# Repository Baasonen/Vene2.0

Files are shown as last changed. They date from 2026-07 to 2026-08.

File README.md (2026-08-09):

<p align="center">
  Vene2.0
</p>

# Vene 2.0

Next evolution of the VENE project, with longer range LoRa communication and improved electronics design. Everything designed to be easily customizable and 3D printed.

## Performance

| Spec | Value |
|---|---|
| Radio Range | ?? km |
| Max Range | ?? km |
| Runtime | ?? min |
| Length | 0.85 m |
| Weight (without payload) | ~3 kg |
| Payload Capacity | ?? kg |
| Payload Dimensions | 130 × 250 × 60 mm* |
| Battery | 3S 6 Ah LiPo |

*Taller height possible with a custom lid

## VGUI2

<p align="center">
  VGUI2
</p>

---

Custom control software for Vene2.0 with multiple map and telemetry options, all easily modifiable.

- Plug & Play operation
- Flexible controller input options
- Route & Scan pattern editing
- Live telemetry & control

***

### Required Hardware

**Boat**
- ESP32
- RFM95W
- u-blox NEO GPS module (NEO-6M currently used; other UBX modules are plug-and-play compatible)
- BNO085
- 3S LiPo
- Generic BLDC motor and ESC
- LiPo → 5V buck converter
- Propeller shaft (RC stuffing box)
- APA106 LEDs (2×, 8 mm package)

**Receiver**
- ESP32
- RFM95W

## Gallery

<p align="center">
  <a href="https://youtu.be/8FJDHWQ4yFw">
    
  </a>
  <a href="https://youtu.be/eb7XCqz7wDQ">
    
  </a>
</p>

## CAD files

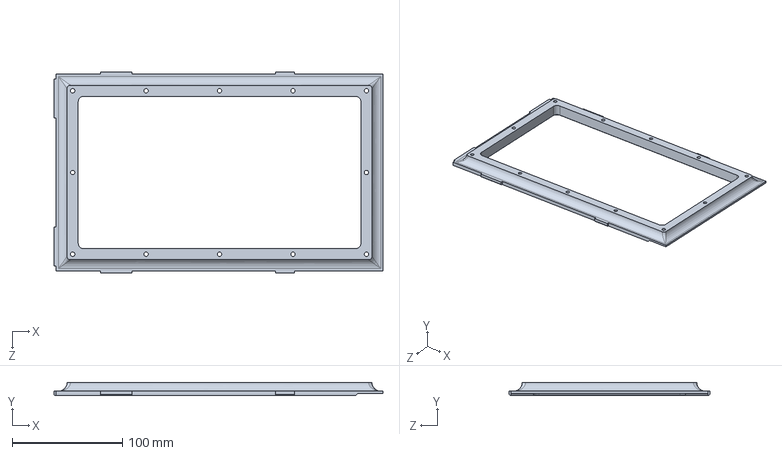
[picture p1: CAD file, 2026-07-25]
CAD/MAIN_HATCH.SLDPRT
297.9 x 12.0 x 181.8 mm

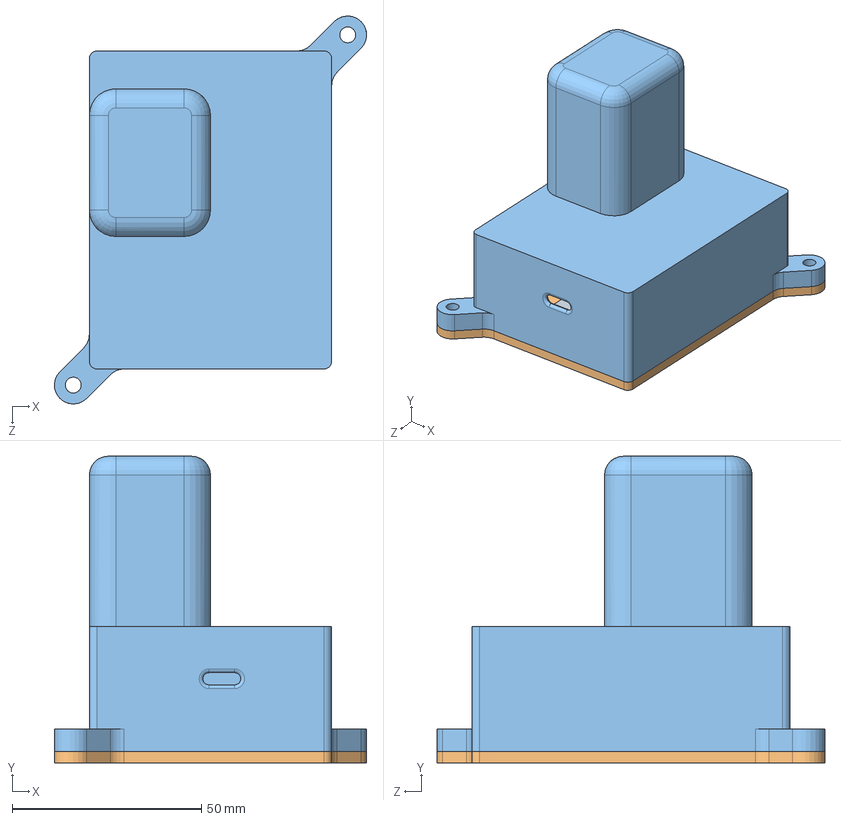
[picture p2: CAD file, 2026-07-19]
CAD/REC_HOUSING.SLDASM
82.5 x 81.0 x 102.5 mm
REC_HOUSING_TOP
REC_HOUSING_BOTTOM
REC_HOLDER

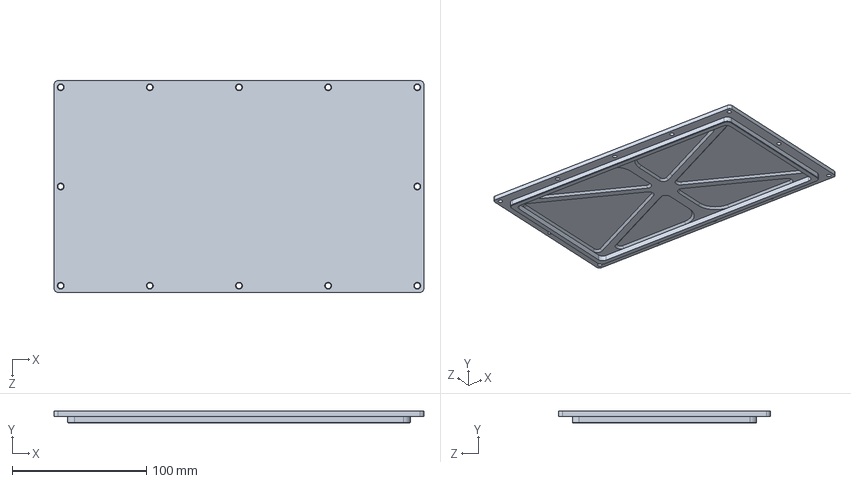
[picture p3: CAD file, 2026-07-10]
CAD/MAIN_HATCH_COVER.SLDPRT
276.0 x 9.00 x 158.0 mm

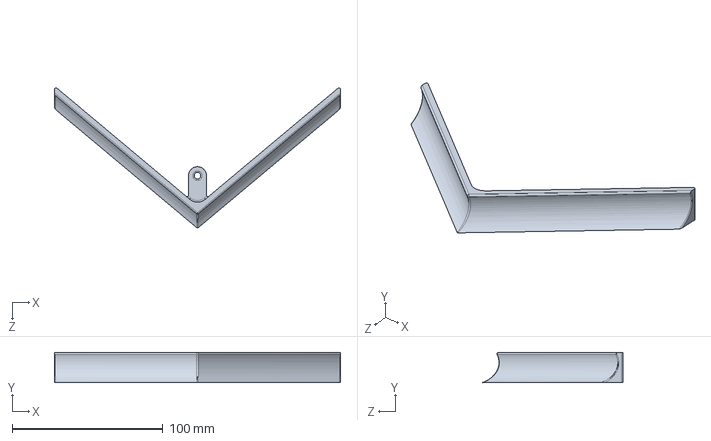
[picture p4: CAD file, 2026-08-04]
CAD/BOW_PLOW.SLDPRT
190.0 x 20.0 x 93.2 mm

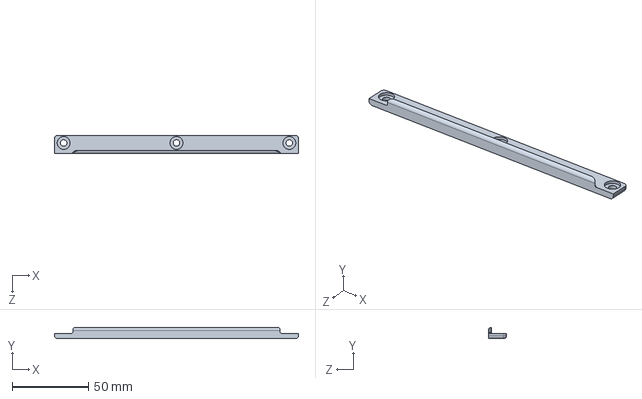
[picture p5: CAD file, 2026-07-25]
CAD/HATCH_BRIM_REAR.SLDPRT
160.0 x 7.50 x 12.0 mm

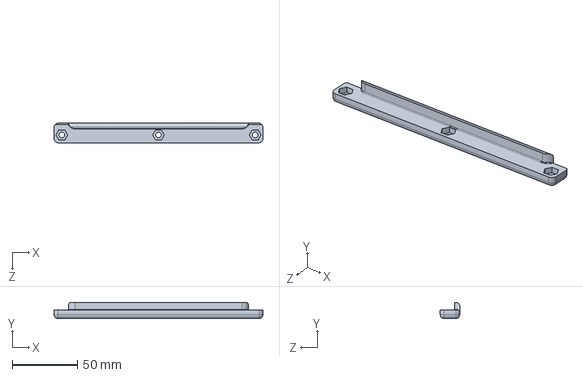
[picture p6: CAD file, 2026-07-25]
CAD/HATCH_BRIM_FRONT.SLDPRT
160.0 x 12.5 x 15.0 mm

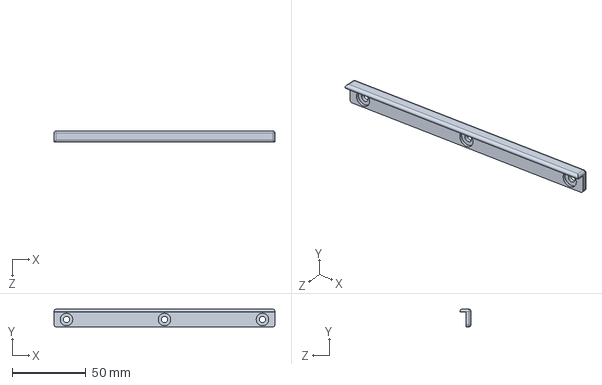
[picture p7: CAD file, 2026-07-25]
CAD/HATCH_BRIM_SIDE.SLDPRT
150.0 x 12.0 x 7.50 mm

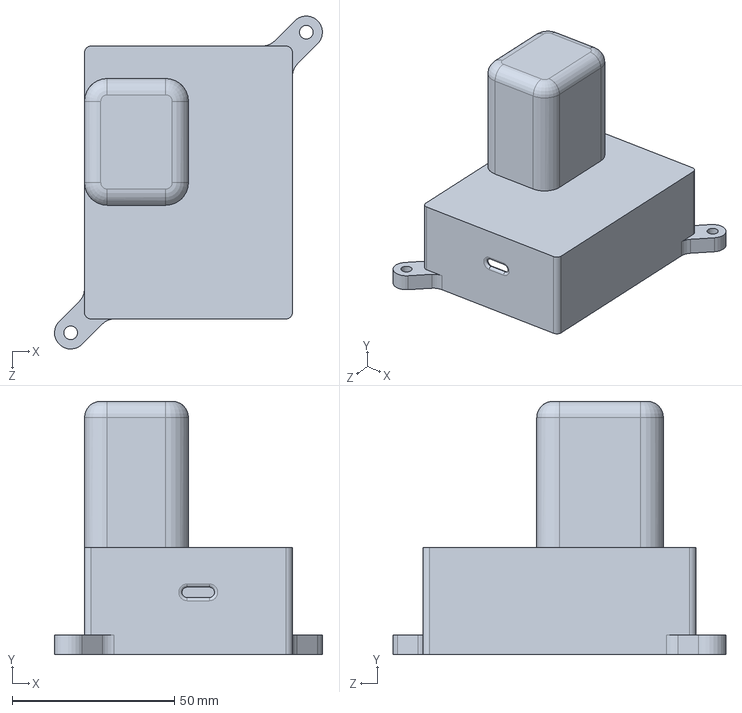
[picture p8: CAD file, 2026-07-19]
CAD/REC_HOUSING_TOP.SLDPRT
82.5 x 78.0 x 102.5 mm

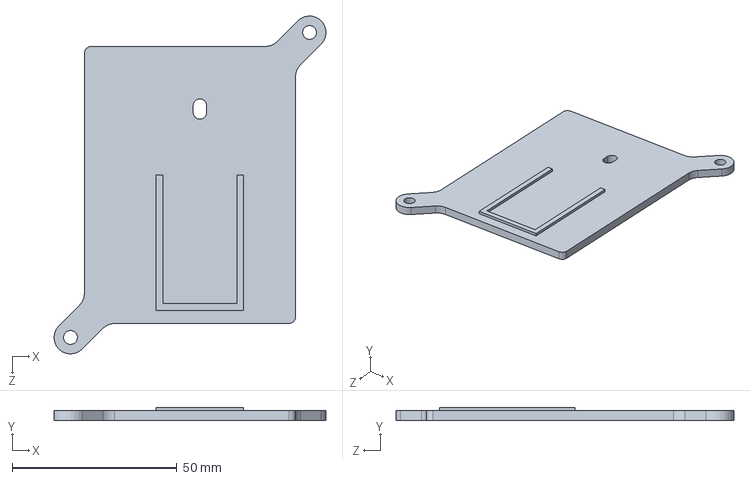
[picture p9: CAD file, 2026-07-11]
CAD/REC_HOUSING_BOTTOM.SLDPRT
82.5 x 4.00 x 102.5 mm

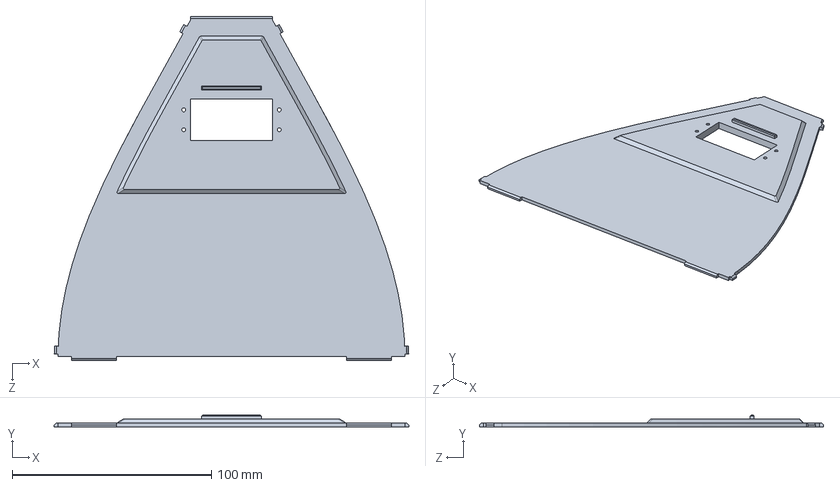
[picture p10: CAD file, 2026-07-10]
CAD/AFT_DECK.SLDPRT
178.1 x 6.00 x 172.8 mm

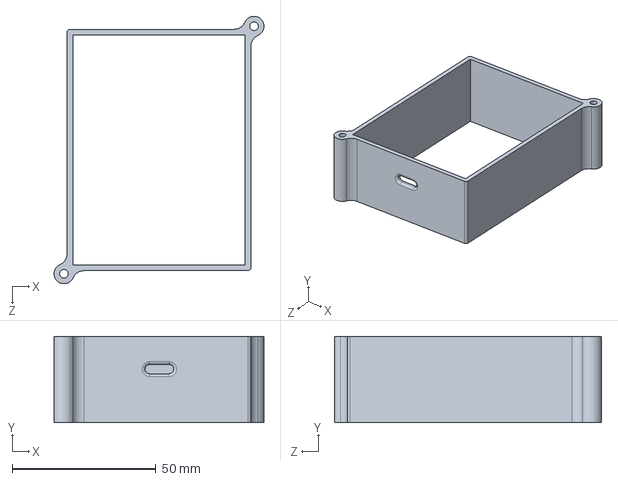
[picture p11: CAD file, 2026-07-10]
CAD/RECEIVER_HOUSING_BASE.SLDPRT
73.1 x 30.0 x 93.1 mm

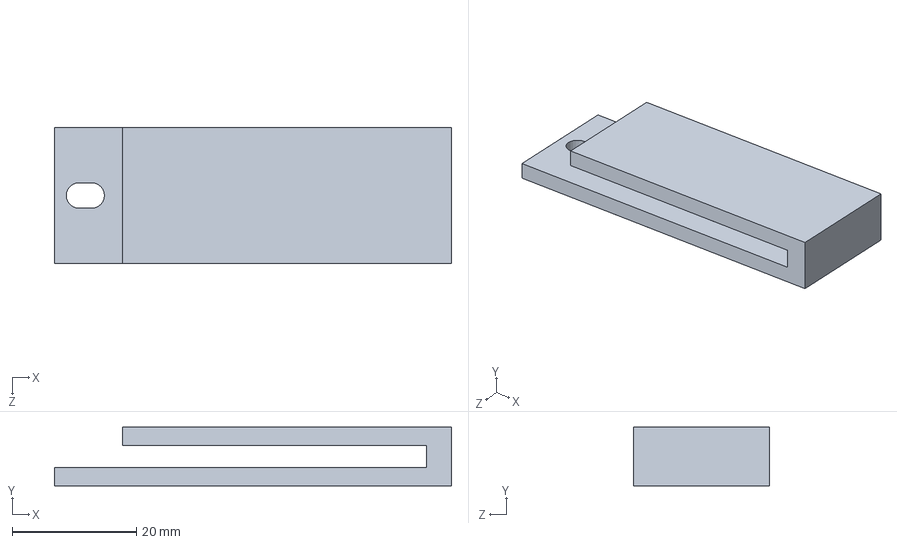
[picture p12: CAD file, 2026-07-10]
CAD/REC_HOLDER.SLDPRT
64.0 x 9.50 x 22.0 mm

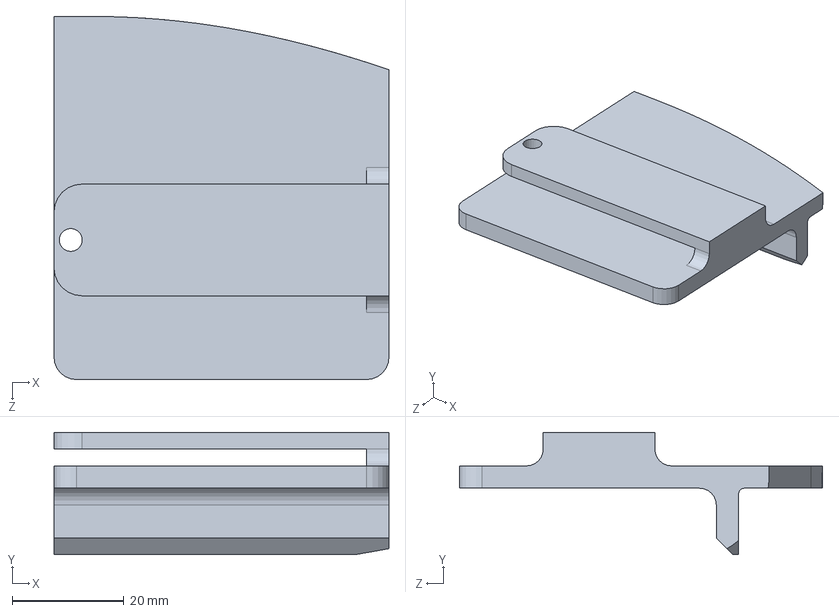
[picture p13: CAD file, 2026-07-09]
CAD/ESP_HOLDER.SLDPRT
60.0 x 21.9 x 65.0 mm

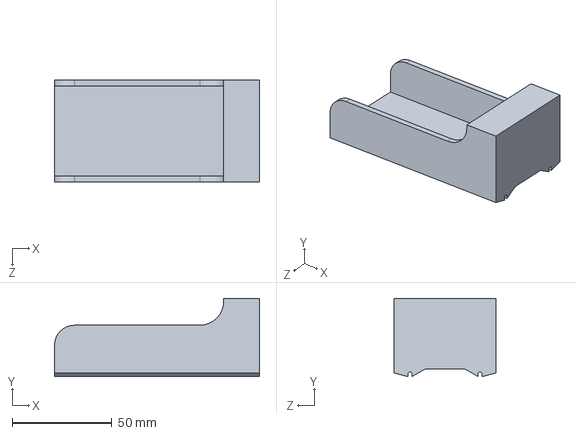
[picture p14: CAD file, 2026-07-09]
CAD/BATTER_HOLDER.SLDPRT
103.0 x 39.4 x 51.0 mm

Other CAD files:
CAD/VENE.SLDASM
CAD/HULLBOW.SLDPRT
CAD/MAST_DECK_ATTACHMENT.SLDPRT
CAD/HULLAFT_2.SLDPRT
CAD/AFT_DECK.STL
CAD/AFT_DECK_GUIDE.SLDPRT
CAD/BATTER_HOLDER.STL
CAD/BOW_PLOW.STL
CAD/Body1.SLDPRT
CAD/Body2.SLDPRT
CAD/ESP_HOLDER.STL
CAD/GPS_SHROUD.SLDPRT
CAD/GPS_SHROUD.STL
CAD/HATCH_BRIM_FRONT.STL
CAD/HATCH_BRIM_REAR.STL
CAD/HATCH_BRIM_SIDE.STL
CAD/HULLAFT_2.STL
CAD/HULLBOW.STL
CAD/HULLMID.SLDPRT
CAD/HULLMID.STL
CAD/LORA_DOME.SLDPRT
CAD/LORA_DOME.STL
CAD/MAIN_HATCH.STL
CAD/MAIN_HATCH_COVER.STL
CAD/MAST.SLDPRT
CAD/MAST_DECK_ATTACHMENT.STL
CAD/MAST_END.SLDPRT
CAD/MAST_END.STL
CAD/MAST_END_COVER.SLDPRT
CAD/MAST_END_COVER.STL
CAD/MOTORBASE1.SLDPRT
CAD/MOTORBASE1.STL
CAD/MOTORMOUNT_GUIDE.SLDPRT
CAD/MOTORMOUNT_GUIDE.STL
CAD/MOTORPLACEHOLDER.SLDPRT
CAD/NEO_6M_ANTENNA_BRACKET.SLDPRT
CAD/NEO_6M_ANTENNA_BRACKET.STL
CAD/NEO_6M_BRACKET.SLDPRT
CAD/NEO_6M_BRACKET.STL
CAD/PROP_COLLIDER.SLDPRT
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

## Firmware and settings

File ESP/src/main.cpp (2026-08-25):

#include <Arduino.h>
#include <ESP32Servo.h>
#include <Preferences.h>

#include "esp_system.h"
#include "esp_task_wdt.h"

#include "freertos/FreeRTOS.h"
#include "freertos/task.h"
#include "freertos/queue.h"
#include "freertos/semphr.h"

#include "magnetometer.h"
#include "gps.h"
#include "lora.h"
#include "state.h"
#include "control.h"
#include "wifiComm.h"
#include "navigation.h"
#include "errors.h"
#include "autopilot.h"
#include "led.h"
#include "LKF.h"
#include "tuning.h"

#define WDT_TIMEOUT 5

Preferences prefs;

State globalState = {0};
SemaphoreHandle_t stateMutex;
QueueHandle_t sensorQueue;

// CORE 1 | PRIORITY 4 | 50HZ
void sensorTask(void* pv)
{
    TickType_t xLastWakeTime = xTaskGetTickCount();
    const TickType_t xPeriod = pdMS_TO_TICKS(20);

    for(;;)
    {
        vTaskDelayUntil(&xLastWakeTime, xPeriod);

        SensorData data;
        data.gps = getGPS();
        data.mag = getMagnetometer();

        data.kf = LKFUpdate(data.gps, data.mag);

        xQueueOverwrite(sensorQueue, &data);

        Battery newBatt = getBattery();

        if (xSemaphoreTake(stateMutex, pdMS_TO_TICKS(10)) == pdTRUE)
        {
            globalState.battery = newBatt;

            xSemaphoreGive(stateMutex);
        }
    }
}

// CORE 1 | PRIORITY 3 | 20HZ
void controlTask(void* pv)
{
    esp_task_wdt_add(NULL);
 
    TickType_t xLastWakeTime = xTaskGetTickCount();
    const TickType_t xPeriod = pdMS_TO_TICKS(50); 
    SensorData sensors = {};
    SystemStatus status = {};
    ManualControls manual = {};
    Route route  = {};

    uint8_t lastMode = 255;
 
    for (;;)
    {
        vTaskDelayUntil(&xLastWakeTime, xPeriod);
        esp_task_wdt_reset();
 
        xQueuePeek(sensorQueue, &sensors, 0);

        if (xSemaphoreTake(stateMutex, pdMS_TO_TICKS(10)) == pdTRUE)
        {
            status = globalState.status;
            manual = globalState.manual;
 
            route = globalState.route;
            globalState.route.newRouteAvailable = false;
 
            xSemaphoreGive(stateMutex);
        }
 
        uint8_t mode = validateMode(status, sensors);

        if (mode != lastMode) {resetSteering();} // Reset steering PI controller on mode change 

        bool justArmed = (mode != 0) && !status.ctrlArmed;
 
        switch (mode)
        {
            case 0: // STOP
                turnRudder(0);
                setThrottle(0);
                break;
 
            case 1: // MANUAL
                turnRudder(manual.rudder);
                setThrottle(manual.throttle);
                break;
 
            case 2: // AUTOPILOT
                if (runAutopilot(status, sensors, route)) {mode = 0;}

                break;
 
            case 3: // RETURN HOME
                
                if (distanceToPoint(status.home.lat, status.home.lon, sensors.kf.lat, sensors.kf.lon) > HOME_TRESHOLD_M)
                {
                    setThrottle(status.APThrottle);
                    steerTo(headingToPoint(sensors.kf.lat, sensors.kf.lon, status.home.lat, status.home.lon));
                }
                else
                {
                    turnRudder(0);
                    setThrottle(0);
                }

                break;

            case 4: // COURSE HOLD
                steerTo(status.targetCourse);
                setThrottle(status.APThrottle);

                break;
 
            default:
                turnRudder(0);
                setThrottle(0);
                break;
        }
 
        if (xSemaphoreTake(stateMutex, pdMS_TO_TICKS(10)) == pdTRUE)
        {
            globalState.sensors = sensors;
            globalState.status.mode = mode;
            globalState.status.targetWaypoint = status.targetWaypoint;

            if (justArmed) {globalState.status.ctrlArmed = true;}
            
            xSemaphoreGive(stateMutex);
        }

        lastMode = mode;
    }
}

// CORE 1 | PRIORITY 2 | 20HZ
void wifiTask(void* pv)
{
    for(;;)
    {
        WiFiReadIncoming(stateMutex);
        vTaskDelay(pdMS_TO_TICKS(50));
    }
}

// CORE 0 | PRIORITY 1 | 0.5 HZ
void diagTask(void* pv)
{
    uint32_t startMillis = millis();

    for(;;)
    {
        vTaskDelay(pdMS_TO_TICKS(2000));

        SensorData sensors = {};
        SystemStatus status = {};
        Battery batt = {};

        xQueuePeek(sensorQueue, &sensors, 0);

        if (xSemaphoreTake(stateMutex, pdMS_TO_TICKS(10)) == pdTRUE)
        {
            status = globalState.status;
            batt = globalState.battery;

            xSemaphoreGive(stateMutex);
        }

        if (millis() - startMillis > 10000)
        {
            Serial.println("\n--- VENE 2.0 ---");
            Serial.printf("Mode:    %u\n", status.mode);
            Serial.printf("GPS:     [%s]  %.6f, %.6f  Sats: %d  HACC: %.2f KF POS STD: %.2f\n",
                          sensors.kf.valid ? "OK " : "BAD",
                          sensors.kf.lat, sensors.kf.lon,
                          sensors.gps.satellites, sensors.gps.hAccM, sensors.kf.posStdM);
            Serial.printf("KF NIS: pos: %.2f vel: %.2f\n", sensors.kf.posNISAvg, sensors.kf.velNIS);
            Serial.printf("Heading: [%s]  %.1f deg  Acc: %u/3\n",
                          sensors.mag.valid ? "OK " : "BAD",
                          sensors.mag.heading, sensors.mag.accuracy);
            Serial.printf("Time: [%s] %d\n", sensors.gps.utcTimeValid ? "GPS" : "REC", status.unixTime);
            Serial.printf("Comms:   LoRa TO: %s  WiFi TO: %s\n",
                          status.loraTimeout ? "YES" : "NO",
                          status.wifiTimeout ? "YES" : "NO");
            Serial.printf("LoRa RSSI: %i dBm\n\n", status.loraRSSI);
            Serial.printf("Battery: %.2f, %.2f, %.2f\n", batt.c1F, batt.c2F, batt.c3F);
            Serial.printf("Errors: 0x%08X\n", (unsigned long)status.errorCode);
            //printActiveErrors();
            Serial.println("----------------");
        }
    }
}

void ledTask(void* pv)
{
    // LED 0: Top
    // LED 1: Bottom

    static LedDoubleFlash bottomBlink;
    static LedPulse bottomCritBlink;
    static LedPulse topSlowBlink;

    static bool dBlink = false;
    static bool critBlinkStarted = false;
    static bool topBlinkStarted = false;
    static bool critErr = false;
    static bool wasCritErr = false;
    static int lastMode = -1;

    for(;;)
    {
        vTaskDelay(pdMS_TO_TICKS(10));

        SystemStatus status = {};

        if (xSemaphoreTake(stateMutex, pdMS_TO_TICKS(10)) == pdTRUE)
        {
            status = globalState.status;

            xSemaphoreGive(stateMutex);
        }

        if (critErr)
        {
            if (!critBlinkStarted || !wasCritErr)
            {
                bottomCritBlink.start(CRGB::Red, 0, 100, 100); // fast blink, 5 Hz
                critBlinkStarted = true;
            }

            leds[1] = bottomCritBlink.update();
        }
        else
        {
            if (!dBlink || wasCritErr)
            {
                bottomBlink.start(CRGB::White, 100, 150, 1600); 
                dBlink = true;
            }

            leds[1] = bottomBlink.update();
        }

        wasCritErr = critErr;

        if (status.mode != lastMode)
        {
            topBlinkStarted = false; // reset blink phase on mode change
        }

        switch (status.mode)
        {
            case 0: // slow blink
                if (!topBlinkStarted)
                {
                    topSlowBlink.start(CRGB::Red, 0, 1500, 500); // 2s period
                    topBlinkStarted = true;
                }

                leds[0] = topSlowBlink.update();
                break;

            case 1:
                leds[0] = CRGB::Red;
                break;

            case 2:
                leds[0] = CRGB::Green;
                break;

            case 3:
                leds[0] = CRGB::Blue;
                break;

            case 4:
                leds[0] = CRGB::Purple;
                break;

            default:
                leds[0] = CRGB::Black;
                break;
        }

        lastMode = status.mode;

        ledShow();
    }
}

void setup()
{
    Serial.begin(115200);
    delay(1000);
    Serial.println("BOOT...");
    delay(500);

    stateMutex = xSemaphoreCreateMutex();
    sensorQueue = xQueueCreate(1, sizeof(SensorData));

    prefs.begin("home", false);
    double savedLat = prefs.getDouble("hLat", 0.0);
    double savedLon = prefs.getDouble("hLon", 0.0);
    prefs.end();

    if (savedLat != 0.0 && savedLon != 0.0) {
        globalState.status.home.lat = savedLat;
        globalState.status.home.lon = savedLon;
        globalState.status.homeSet = true;
        Serial.printf("[PREFS] Loaded Home: %.6f, %.6f\n", savedLat, savedLon);
    }

    bool sensorInitFail = false;

    if (!magInit()) {Serial.println("[INIT] Mag init fail"); sensorInitFail = true;}
    if (!GPSInit()) {Serial.println("[INIT] GPS init failed"); sensorInitFail = true;}

    if (!sensorInitFail) {Serial.println("[INIT] Sensor init OK");}

    LKFInit();

    ledSetup();

    controlInit();
    WiFiInit();

    setError(ERR_INIT);

    esp_task_wdt_init(WDT_TIMEOUT, true);
    esp_task_wdt_add(NULL);

    // CORE 1
    xTaskCreatePinnedToCore(sensorTask, "Sensor", 4096, NULL, 4, NULL, 1);
    xTaskCreatePinnedToCore(controlTask, "Control", 8192, NULL, 3, NULL, 1);
    xTaskCreatePinnedToCore(wifiTask, "WiFi", 4096, NULL, 2, NULL, 1);
    xTaskCreatePinnedToCore(ledTask, "LED", 4096, NULL, 2, NULL, 1);

    // CORE 0
    xTaskCreatePinnedToCore(commsTask, "Comms", 8192, NULL, 2, NULL, 0);
    xTaskCreatePinnedToCore(diagTask, "Diag", 4096, NULL, 1, NULL, 0);
    xTaskCreatePinnedToCore(errorTask, "Error", 4096, NULL, 2, NULL, 0);

    esp_task_wdt_delete(NULL);
    //vTaskDelete(NULL);
}

void loop()
{
    if (globalState.status.homeNeedsSave)
    {
        double hLat = 0.0;
        double hLon = 0.0;

        if (xSemaphoreTake(stateMutex, pdMS_TO_TICKS(10)) == pdTRUE)
        {
            hLat = globalState.status.home.lat;
            hLon = globalState.status.home.lon;
            globalState.status.homeNeedsSave = false;
            xSemaphoreGive(stateMutex);

            prefs.begin("home", false);
            prefs.putDouble("hLat", hLat);
            prefs.putDouble("hLon", hLon);
            prefs.end();

            Serial.println("[PREFS] Saved home wp");
        }
    }

    vTaskDelay(pdMS_TO_TICKS(100));
}

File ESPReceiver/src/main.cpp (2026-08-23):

#include <Arduino.h>
#include <WiFi.h>
#include <WiFiUdp.h>

#include "esp_system.h"

#include "setup.h"

const char* ssid = "VENE2.0";
const char* password = "123456789";
const char* ip = "192.168.4.1";
const int udpTxPort = 4210;
const int udpRxPort = 4211;

#define LORA_TX_TIMEOUT_MS 750

#define CAD_MAX_ATTEMPTS 3
#define CAD_BACKOFF_MIN_MS 2
#define CAD_BACKOFF_MAX_MS 10

WiFiUDP udp;
bool udpReady = false;

SX1276 radio = new Module(LORA_CS, LORA_DIO0, -1, -1);

enum LoRaDir {LORA_DIR_RX, LORA_DIR_TX};
volatile LoRaDir loraDir = LORA_DIR_RX;
static uint32_t txStartTime = 0;

SemaphoreHandle_t rxPacketSem;
SemaphoreHandle_t txDoneSem;

void IRAM_ATTR onLoraDio0Rise()
{
    BaseType_t woken = pdFALSE;

    if (loraDir == LORA_DIR_RX)
    {
        xSemaphoreGiveFromISR(rxPacketSem, &woken);
    }
    else
    {
        xSemaphoreGiveFromISR(txDoneSem, &woken);
    }

    if (woken) {portYIELD_FROM_ISR();}
}

static bool channelClear()
{
    detachInterrupt(digitalPinToInterrupt(LORA_DIO0));

    xSemaphoreTake(rxPacketSem, 0);
    xSemaphoreTake(txDoneSem, 0);

    int16_t cad = radio.scanChannel();

    attachInterrupt(digitalPinToInterrupt(LORA_DIO0), onLoraDio0Rise, RISING);

    return (cad == RADIOLIB_CHANNEL_FREE);
}

void beginTransmit(uint8_t* data, size_t len)
{
    for (int attempt = 0; attempt < CAD_MAX_ATTEMPTS; attempt++)
    {
        if (channelClear()) {break;}

        loraDir = LORA_DIR_RX;
        radio.startReceive();

        uint32_t backoff = CAD_BACKOFF_MIN_MS + (esp_random() % CAD_BACKOFF_MAX_MS);
        vTaskDelay(pdMS_TO_TICKS(backoff));
    }

    radio.standby();

    txStartTime = millis();
    loraDir = LORA_DIR_TX;
    radio.startTransmit(data, len);
}

void completeTransmit()
{
    loraDir = LORA_DIR_RX;
    radio.startReceive();
}

void forceRecoverTxStuck()
{
    Serial.println("[LORA] TX stuck, forcing RX");

    xSemaphoreTake(txDoneSem, 0);
    xSemaphoreTake(rxPacketSem, 0);

    radio.standby();
    loraDir = LORA_DIR_RX;
    radio.startReceive();
    txStartTime = 0;
}

void setup()
{
    Serial.begin(115200);

    rxPacketSem = xSemaphoreCreateBinary();
    txDoneSem = xSemaphoreCreateBinary();

    SPI.begin(LORA_SCK, LORA_MISO, LORA_MOSI, -1);
    int state = radio.begin(LORA_FREQ, LORA_BANDWIDTH, LORA_SF, LORA_CODING_RATE, RADIOLIB_SX127X_SYNC_WORD, LORA_POWER);

    Serial.print("[LORA] LoRa init: ");
    Serial.print(state == RADIOLIB_ERR_NONE ? "OK" : "FAIL");
    Serial.println(state);

    if (state == RADIOLIB_ERR_NONE)
    {
        attachInterrupt(digitalPinToInterrupt(LORA_DIO0), onLoraDio0Rise, RISING);
        loraDir = LORA_DIR_RX;
        radio.startReceive();
    }
    else
    {
        while (true);
    }

    WiFi.mode(WIFI_STA);
    WiFi.begin(ssid, password);

    Serial.println("[REC] Init ready");
}

void loop()
{
    static uint8_t lastWifiStatus = 255;
    uint8_t wifiStatus = WiFi.status();

    if (wifiStatus != lastWifiStatus)
    {
        Serial.print("[WIFI] WiFi status: ");
        Serial.println(wifiStatus);
        lastWifiStatus = wifiStatus;
    }

    if (!udpReady && (wifiStatus == WL_CONNECTED))
    {
        udp.begin(udpRxPort);
        udpReady = true;
        Serial.print("UDP ready, IP: ");
        Serial.println(WiFi.localIP());
    }

    if (xSemaphoreTake(txDoneSem, 0) == pdTRUE)
    {
        completeTransmit();
    }
    else if (loraDir == LORA_DIR_TX && txStartTime != 0 && (millis() - txStartTime) > LORA_TX_TIMEOUT_MS)
    {
        forceRecoverTxStuck();
    }

    if (loraDir == LORA_DIR_RX && xSemaphoreTake(rxPacketSem, 0) == pdTRUE)
    {
        int len = radio.getPacketLength();
        uint8_t rxBuffer[256];
        int state = radio.readData(rxBuffer, len);

        if (state == RADIOLIB_ERR_NONE && len > 0) {Serial.write(rxBuffer, len);}

        if (loraDir == LORA_DIR_RX) {radio.startReceive();}
    }

    if (udpReady)
    {
        int packetSize = udp.parsePacket();

        if (packetSize > 0)
        {
            uint8_t udpData[4];
            udp.read(udpData, sizeof(udpData));

            Serial.write(PKT_WIFI_HEARTBEAT);
            Serial.write(udpData, sizeof(udpData));
        }
    }

    if (Serial.available() > 0)
    {
        uint8_t id = Serial.peek();
        int expectedLen = 0;

        if (id == PKT_WP_DATA) {expectedLen = ROUTE_PACKET_SIZE;}
        else if (id == PKT_CONTROL) {expectedLen = CONTROL_PACKET_SIZE;}
        else if (id == PKT_MANUAL) {expectedLen = MANUAL_SERIAL_SIZE;}
        else if (id == PKT_DATA) {expectedLen = PKT_DATA_SIZE;}
        else if (id == PKT_RESET_ERRORS) {expectedLen = RESET_ERRORS_SIZE;}
        else if (id == PKT_HOME_SET) {expectedLen = HOME_SET_SIZE;}
        else if (id == PKT_HOME_REQ) {expectedLen = HOME_REQ_SIZE;}
        else if (id == PKT_TIME_DATA) {expectedLen = TIME_DATA_SIZE;}
        else if (id == PKT_COURSE_SET) {expectedLen = COURSE_SET_SIZE;}
        else if (id == PKT_UPLOAD_BEGIN) {expectedLen = UPLOAD_BEGIN_SIZE;}
        else if (id == PKT_THR_SET) {expectedLen = THR_SET_SIZE;}
        else
        {
            Serial.read(); // Discard unknown
            return;
        }

        bool isLoraPacket = (id == PKT_WP_DATA || id == PKT_CONTROL || id == PKT_DATA ||
                              id == PKT_RESET_ERRORS || id == PKT_HOME_SET || id == PKT_HOME_REQ ||
                              id == PKT_TIME_DATA || id == PKT_COURSE_SET || id == PKT_THR_SET ||
                              id == PKT_UPLOAD_BEGIN);

        if (isLoraPacket && loraDir == LORA_DIR_TX) {return;} // If already transmiting leave bytes in serial buffer

        if (Serial.available() >= expectedLen)
        {
            uint8_t txBuffer[64];
            Serial.readBytes(txBuffer, expectedLen);

            if (isLoraPacket)
            {
                static uint32_t lastLoraTx = 0;

                if (id == PKT_DATA && (millis() - lastLoraTx) < 400)
                {
                    // Discard too early hb
                }
                else
                {
                    lastLoraTx = millis();
                    beginTransmit(txBuffer, expectedLen);
                }
            }

            else if (id == PKT_MANUAL)
            {
                if (WiFi.status() == WL_CONNECTED)
                {
                    udp.beginPacket(ip, udpTxPort);
                    udp.write(&txBuffer[1], 2);
                    udp.endPacket();
                }
            }
        }
    }
}

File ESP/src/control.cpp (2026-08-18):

#include "control.h"

static Servo rudder;
static Servo motor;

static float iError = 0.0f;
static uint32_t lastSteerTime = 0;

void resetSteering()
{
    iError = 0.0f;
    lastSteerTime = 0;
}

void controlInit()
{
    rudder.attach(RUDDER_PIN);
    rudder.write(90);

    motor.attach(ESC_PIN);
    motor.writeMicroseconds(ESC_NEUTRAL);
}

void turnRudder(int8_t angle)
{
    if (angle > RUDDER_U_LIM) {angle = RUDDER_U_LIM;}
    if (angle < RUDDER_L_LIM) {angle = RUDDER_L_LIM;}

    rudder.write(angle + 85); // Should be 90, quick fix to center rudder
}

void setThrottle(int8_t throttle)
{
    if (abs(throttle) < 5) {throttle = 0;}

    if (throttle < 0) {throttle /= ESC_REVERSE_DIV;}

    uint32_t throttleMS = (uint32_t)((float)(throttle * ESC_RANGE) + ESC_NEUTRAL);
    motor.writeMicroseconds(throttleMS);
}

void steerTo(float targetHeading)
{
    const float Kp = RUDDER_KP;
    const float Ki = RUDDER_KI;
    const float deadzone = 2.0f;
    const float integralLimit = RUDDER_I_LIM;

    float currentHeading = 0.0f;

    if (xSemaphoreTake(stateMutex, pdMS_TO_TICKS(10)) == pdTRUE)
    {
        currentHeading = globalState.sensors.mag.heading;
        xSemaphoreGive(stateMutex);
    }

    float error = targetHeading - currentHeading;
    if (error > 180.0f) {error -= 360.0f;}
    if (error < -180.0f) {error += 360.0f;}

    uint32_t now = millis();
    float dt = (lastSteerTime == 0) ? 0.05f : (now - lastSteerTime) / 1000.0f;
    lastSteerTime = now;

    if (abs(error) < deadzone) 
    {
        turnRudder(0);

        return;
    }

    float rawAngle = (error * Kp) + (iError * Ki);
    bool saturated = (rawAngle > RUDDER_U_LIM) || (rawAngle < RUDDER_L_LIM);

    if (!saturated)
    {
        iError += error * dt;
        if (iError > integralLimit) {iError = integralLimit;}
        if (iError < -integralLimit) {iError = -integralLimit;}
    }

    if (rawAngle > RUDDER_U_LIM) {rawAngle = RUDDER_U_LIM;}
    if (rawAngle < RUDDER_L_LIM) {rawAngle = RUDDER_L_LIM;}

    turnRudder((int8_t)rawAngle);
}

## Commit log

2026-04-26 Boat to computer communication working & test gui
    [Mid1.STL, Proto.SLDPRT]
2026-05-06 Hull model progress
    [Body1.SLDPRT, Body2.SLDPRT, HULLBOW.SLDPRT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]
2026-05-17 CAD updates
    [HULLAFT_2.SLDPRT, HULLAFT_2.STL, HULLBOW.SLDPRT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]
2026-05-25 Model updates & transition completely to freeRTOS
    [AFT_DECK.SLDPRT, AFT_DECK.STL, AFT_DECK_GUIDE.SLDPRT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]
2026-05-25 VGUI updates, error display
    [lora.cpp, main.cpp, setup.h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]
2026-06-03 Lora & model updates
    [GPS_SHROUD.STL, HULLAFT_2.SLDPRT, HULLBOW.SLDPRT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]
2026-06-17 Working error system & vgui progress
    [errors.cpp, gps.cpp, lora.cpp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]
2026-06-25 Fixed route upload bug
    [vcom.py]
2026-07-09 CAD updates & LoRa reset changes
    [AFT_DECK.SLDPRT, BATTER_HOLDER.SLDPRT, BATTER_HOLDER.STL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]
2026-07-10 Support for course hold mode, total route length display & UI bugfixes
    [AFT_DECK.SLDPRT, AFT_DECK.STL, MAIN_HATCH_COVER.SLDPRT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]
2026-07-11 Added LOS to improve A/P accuracy on longer legs between waypoints
    [REC_HOUSING_BOTTOM.SLDPRT, REC_HOUSING_BOTTOM.STL, REC_HOUSING_TOP.SLDPRT]
2026-07-16 Transmit UPLOAD_BEGIN to prepare for receiving wp packets
    [VENE.SLDASM]
2026-07-17 Bugfixes & timestamp on log
    [packet_handlers.cpp, protocol.py, vcom.py]
2026-07-19 Lora config & rec housing uodates
    [REC_HOUSING.SLDASM, REC_HOUSING_TOP.SLDPRT, REC_HOUSING_TOP.STL]
2026-07-21 Refactored steerTo() to include PI controller and fixed overflows
    [control.cpp, main.cpp, setup.h]
2026-07-21 Water ingress sensor integration into error task
    [errors.cpp]
2026-07-25 Added adjustable A/P throttle
    [HATCH_BRIM_REAR.SLDPRT, HATCH_BRIM_REAR.STL, HATCH_BRIM_SIDE.SLDPRT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]
2026-07-25 More map modes & sea charts
    [HATCH_BRIM_FRONT.SLDPRT, HATCH_BRIM_FRONT.STL, HATCH_BRIM_REAR.SLDPRT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]
2026-07-27 LED controll
2026-07-27 Led config changes
2026-07-31 Error frame bugfixes
2026-07-31 Forgot to disable debugger as default ☠️
2026-08-01 Led updates
2026-08-01 Led bugfix
    [BOW_PLOW.SLDPRT, VENE.SLDASM]
2026-08-04 Moved from tinygps to custom ubx parsing
    [BOW_PLOW.SLDPRT, BOW_PLOW.STL, VENE.SLDASM]
2026-08-04 Moved led control from fastLED to a custom driver
2026-08-07 Fixed lora stuck in reinit
    [lora.cpp]
2026-08-09 Lora rec update & bugfixes
    [lora.cpp, main.cpp]
2026-08-15 Kalman filter for gps pos
2026-08-18 Bugfixes & updated gitignore
    [control.cpp, tuning.h]
2026-08-23 CAD to lora beginTransmit
2026-08-23 Switched imu report type
2026-08-24 Battery monitor for 3S lipo
2026-08-25 Battery monitor configuration
2026-08-28 Revamped battery telemetry readout
2026-08-29 Updated battery gains
